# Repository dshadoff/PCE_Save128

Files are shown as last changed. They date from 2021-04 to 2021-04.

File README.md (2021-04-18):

# PCE_Save128
FPGA Implementation of reverse-engineered Memory Base 128/Save-Kun device

This project is designed to reimplement the features of the PC Engine's
Save-kun or Memory Base 128 devices in a modern FPGA device rather than a
customized ASIC.

SPI FeRAM is also in use, with the benefit of being non-volatile.

A MachXO2 FPGA was used due to its relatively low cost, internal Flash
reprogrammability, and simple power supply requirements. Additionally, the
TinyFPGA Ax-series of hobbyist boards helped to facilitate the prototyping
process.

The firmware is coded in Veriog using Lattice's Diamond software; the on-chip
SPI interface was not used; instead, a very limited set of SPI commands is
custom-written for communication with the FeRAM chip.

This repository includes the following folders:

EAGLE :
- these files are the project deisgn files for the PC Board in EAGLE
- Additional information for SMD assembly by JLCPCB are also included, files bom.csv and assembly.csv

firmware:
- This is the project folder for Lattice Diamond, using a MachXO2 FPGA of part number "LCMXO2-1200HC-4SG32C" - as found in the TinyFPGA AX2 board (which is used as a sub-assembly)
- key files are:
 - Save128.v - main verilog file
 - top.v - the top-level module
 - Save128.lpf - pin assignment settings file
 - testbench.v - a testbench which assists in visualizing various scenarios in simulation

release:
- Includes both an SRAM image (.bit) and Flash image (.jed).
- Filename base ends in "yyyymmdd" date format.

TODOs:
------
- shrink PC board
- possibly integrate the FPGA directly onto the main PC board
- design an enclosure of some sort

This is prototype software, and as such has been minimally tested.
Use at your own risk.

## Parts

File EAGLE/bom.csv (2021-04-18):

Qty | Designator | Footprint | Comment | LCSC Part # (optional) | Description (optional)
1 | J1 | CONN_08";1X08" | Do not mount | Do not mount | Multi connection point. Often used as Generic Header-pin footprint for 0.1 inch spaced/style header connections
2 | J2, J3 | MD80SGK | Do not mount | Do not mount | Circular DIN Connectors mini-DIN, 8P jack, rt, through hole, full shield
2 | J4, J5 | 1X12 | Do not mount | Do not mount | Multi connection point. Often used as Generic Header-pin footprint for 0.1 inch spaced/style header connections
1 | J6 | 1X02 | Do not mount | Do not mount | Multi connection point. Often used as Generic Header-pin footprint for 0.1 inch spaced/style header connections
1 | J7 | 1X06_NO_SILK | Do not mount | Do not mount | Multi connection point. Often used as Generic Header-pin footprint for 0.1 inch spaced/style header connections
8 | C1, C2, C6, C7, C8, C9, C10, C11 | C0603 | 0.1uF 50V | C14663 | Yageo CC0603KRX7R9BB104 100NF 50V 0603
2 | C3, C4 | C0603 | 1uF 50V | C15849 | Samsung CL10A105KB8NNNC 1uF 50V 0603
1 | C5 | C0805 | 10uF 25V | C15850 | Samsung CL21A106KAYNNNE 10uF 25V 0805
1 | LED1 | LEDC1608X60N | Yellow | C72038 | Everlight Elec 19-213/Y2C-CQ2R2L/3T(CY) 0603
1 | LED2 | LEDC1608X50N | Green | C72043 | Everlight Elec 19-217/GHC-YR1S2/3T 0603
1 | LED3 | LEDC1608X50N | Red | C2286 | Hubei KENTO Elec KT-0603R 0603
1 | R1 | R0603 | 4.7K | C23162 | Uniroyal Elec 0603WAF4701T5E 0603
5 | R2, R21, R22, R23, R24 | R0603 | 47K | C25819 | Uniroyal Elec 0603WAF4702T5E 0603
2 | R3, R15 | R0603 | 3.3K | C22978 | Uniroyal Elec 0603WAF3301T5E 0603
5 | R13, R16, R18, R19, R20 | R0603 | 330 | C23138 | Uniroyal Elec 0603WAF3300T5E 0603
3 | IC1, IC2, IC3 | SM-8_2.8x3.0x0.65P | SN74LVC2T45DCTR | C22672 | 2-Bit Bus Transceiver, Translation SSOP8 SN74LVC2T45DCTR, Voltage Level Translator, Bus Transceiver LVC, 3-State 1.65
1 | IC4 | SOIC-8_3.9x4.9x1.27P | FM25V10-G | C44173 | F-RAM,128KB,SPI,40MHz,3V,SOIC8 FM25V10-G Serial-SPI FRAM Memory, 1Mbit, 2 3.6 V 8-Pin SOIC
1 | IC5 | SOIC-16_3.9x9.9x1.27P | SN74HC157D | C6823 | Quadruple 2-Line To 1-Line Data Selectors/Multiplexers
1 | IC6 | SOT-23-3 | MCP1700T-3302E_TT | C39051 | LDO voltage regulator 250mA Isupply 1uA

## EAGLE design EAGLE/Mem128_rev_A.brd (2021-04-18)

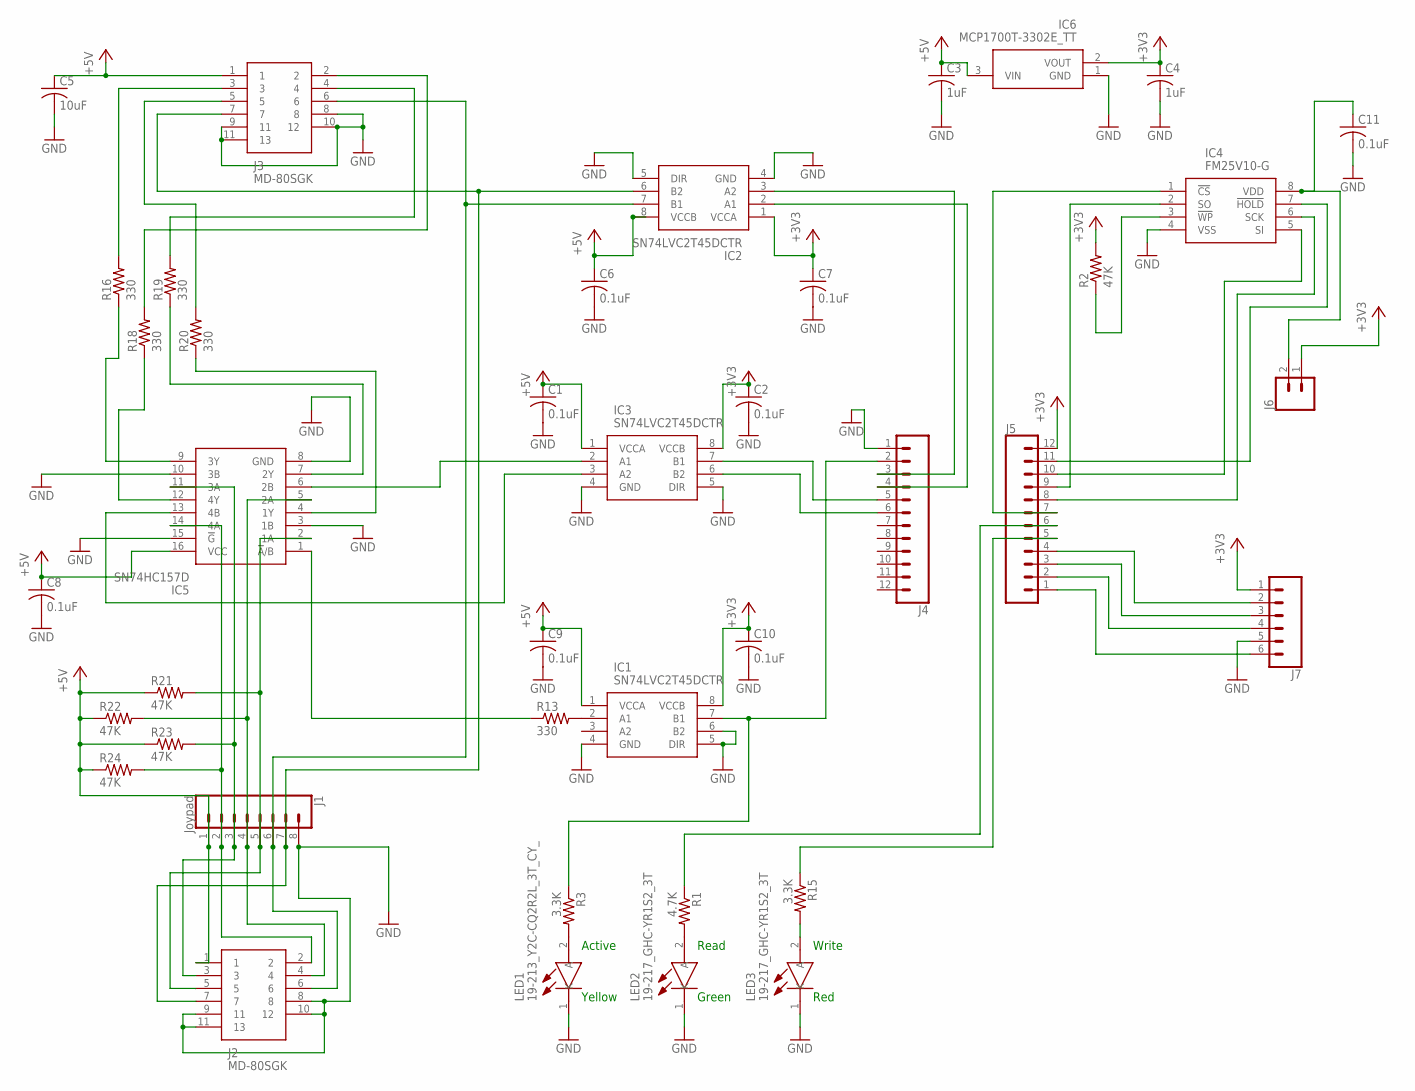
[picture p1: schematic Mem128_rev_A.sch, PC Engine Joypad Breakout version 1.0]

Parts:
C1, C2, C6, C7, C8, C9, C10, C11: 0.1uF; C0603
C3, C4: 1uF; C0603
C5: 10uF; C0805
IC1, IC2, IC3: SN74LVC2T45DCTR; SOP65P400X130-8N
IC4: FM25V10-G; SOIC127P602X173-8N
IC5: SN74HC157D; SOIC127P600X175-16N
IC6: MCP1700T-3302E_TT; SOT95P237X112-3N
J1: Joypad; 1X08
J2, J3: MD-80SGK; MD80SGK
J4, J5: CONN_12; 1X12
J6: CONN_02; 1X02
J7: CONN_06NO_SILK_FEMALE_PTH; 1X06_NO_SILK
LED1: 19-213_Y2C-CQ2R2L_3T_CY_; LEDC1608X60N
LED2: 19-217_GHC-YR1S2_3T; LEDC1608X50N
LED3: 19-217_GHC-YR1S2_3T; LEDC1608X50N; MANUFACTURER_PART_NUMBER KT-0603R
R1: 4.7K; R0603
R2, R21, R22, R23, R24: 47K; R0603
R3, R15: 3.3K; R0603
R13, R16, R18, R19, R20: 330; R0603

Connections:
+3V3: C2.1, C4.1, C7.1, C10.1, IC1.8 (VCCB), IC2.1 (VCCA), IC3.8 (VCCB), IC6.2 (VOUT), J5.12, J6.1, J7.1, R2.2
+5V: C1.1, C3.1, C5.1, C6.1, C8.1, C9.1, IC1.1 (VCCA), IC2.8 (VCCB), IC3.1 (VCCA), IC5.16 (VCC), IC6.3 (VIN), J1.1, J2.1, J3.1, R21.1, R22.1, R23.1, R24.1
CLR: IC2.6 (B2), J1.7, J2.7, J3.7
D6: J5.5, R15.1
D10: J5.6, R1.1
D11: IC1.7 (B1), J4.2, R3.1
GND: C1.2, C2.2, C3.2, C4.2, C5.2, C6.2, C7.2, C8.2, C9.2, C10.2, C11.2, IC1.4 (GND), IC1.5 (DIR), IC1.6 (B2), IC2.4 (GND), IC2.5 (DIR), IC3.4 (GND), IC3.5 (DIR), IC4.4 (VSS), IC5.3 (1B), IC5.8 (GND), IC5.10 (3B), IC5.15 (!G), IC6.1 (GND), J1.8, J2.8, J2.9 (11), J2.10 (12), J2.11 (13), J3.8, J3.9 (11), J3.10 (12), J3.11 (13), J4.1, J7.5, LED1.1 (K), LED2.1 (K), LED3.1 (K)
unnamed: LED2.2 (A), R1.2
unnamed: IC5.11 (3A), J1.3, J2.3, R23.2
unnamed: IC5.14 (4A), J1.2, J2.2, R24.2
unnamed: LED1.2 (A), R3.2
unnamed: IC4.7 (!HOLD), J5.11
unnamed: IC4.6 (SCK), J5.8
unnamed: J3.5, R20.2
unnamed: J3.4, R19.2
unnamed: J3.3, R16.2
unnamed: C11.1, IC4.8 (VDD), J6.2
unnamed: IC5.1 (!A!/B), R13.1
unnamed: IC1.2 (A1), R13.2
unnamed: IC5.5 (2A), J1.4, J2.4, R22.2
unnamed: IC5.9 (3Y), R16.1
unnamed: IC5.2 (1A), J1.5, J2.5, R21.2
unnamed: IC3.2 (A1), IC5.6 (2B)
unnamed: IC5.12 (4Y), R18.1
unnamed: IC5.4 (1Y), R20.1
unnamed: J3.2, R18.2
unnamed: IC5.7 (2Y), R19.1
unnamed: IC4.3 (!WP), R2.1
unnamed: IC4.1 (!CS), J5.7
unnamed: IC4.5 (SI), J5.10
unnamed: IC3.3 (A2), IC5.13 (4B)
unnamed: IC4.2 (SO), J5.9
unnamed: IC2.3 (A2), J4.3
unnamed: IC3.7 (B1), J4.5
unnamed: IC3.6 (B2), J4.6
unnamed: J5.1, J7.6
unnamed: LED3.2 (A), R15.2
unnamed: J5.2, J7.4
unnamed: J5.3, J7.3
unnamed: J5.4, J7.2
RX: IC2.2 (A1), J4.4
SEL: IC2.7 (B1), J1.6, J2.6, J3.6

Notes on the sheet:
Active
Read
Write
Yellow
Green
Red

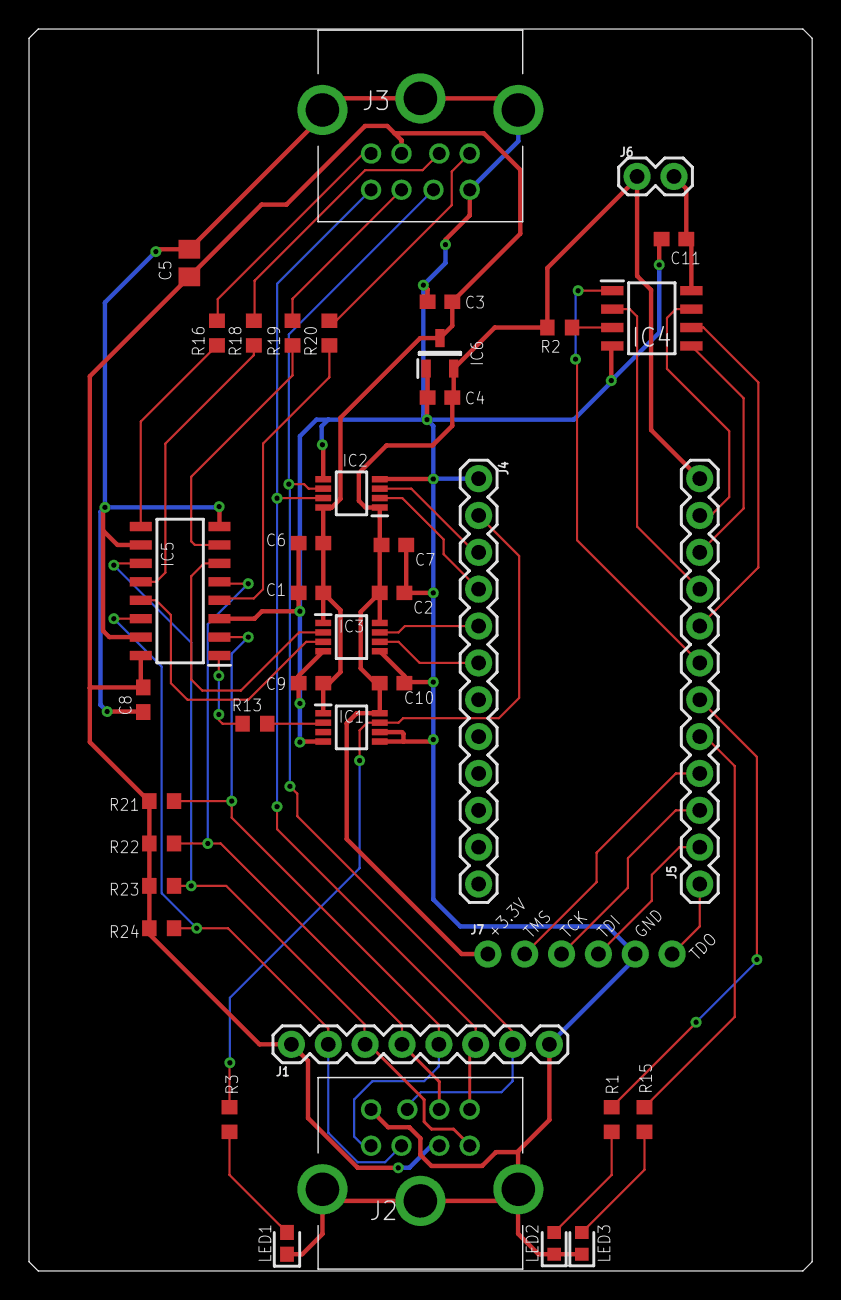
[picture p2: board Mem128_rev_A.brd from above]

Board: 2 copper layers, 54.0 x 85.6 mm, 40 parts (0 on the bottom side), 42 nets.

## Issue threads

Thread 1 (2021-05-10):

iCE40?  Parallel memory?

GravisZro, 2021-05-10:
Just curious if you might be interested in perhaps modifying the project to use a Lattice iCE40 chip (e.g. [ICE40HX1K-VQ100](https://www.digikey.com/en/products/detail/lattice-semiconductor-corporation/ICE40HX1K-VQ100/3083577)) since there is [an open source toolchain](http://www.clifford.at/icestorm/) and perhaps avoid SPI altogether by using a memory chip with a parallel interface (e.g. [MR0A08BYS35](https://www.digikey.com/en/products/detail/everspin-technologies-inc/MR0A08BYS35/1930954)).  Yes, the iCE40 will need another power regulator but it's not too complex.  There is [a cheap iCE40 dev board](http://www.latticesemi.com/icestick) you can get if that is a concern.

Just some ideas to consider but if you're not interested in making changes, that's OK too.

GravisZro, 2021-05-10:
Ugh... QFN is the worst.  Looking forward to the new solution.

Closed 2021-05-10.

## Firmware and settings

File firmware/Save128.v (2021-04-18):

module MB128 (
	input		clk_sys,	// system clock
	input wire	reset_n,	// reset - active low

	input  i_Clk,			// Joypad Clr/Reset line, clocks the SPI-like MB128 protocol 
	input  i_Data,			// Joypad Sel line, provides data to the SPI-like MB128 protocol

	output o_Active,
    output o_Data,
    output o_Ident,

	output o_ReadLED,
	output o_WriteLED,

	output sp_cs_n,
	output sp_clk,
	input  sp_miso,
	output sp_mosi,
	output sp_hold_n
);


  // constants - SPI Commands
  parameter   SPI_READ_CMD		= 8'h3;
  parameter   SPI_WRITE_CMD		= 8'h2;
  parameter   SPI_WREN_CMD		= 8'h6;

  // constants - STATE MACHINE states
  // STATE GROUP 1 - Request identification
  parameter   STATE_IDLE         = 4'b0000;
  parameter   STATE_A8_A1        = 4'b0001;
  parameter   STATE_A8_A2        = 4'b0010;
  // STATE GROUP 2 - Synced; request information
  parameter   STATE_REQ          = 4'b0011;
  parameter   STATE_ADDR         = 4'b0100;
  parameter   STATE_LENBITS      = 4'b0101;
  parameter   STATE_LENBYTES     = 4'b0110;
  // STATE GROUP 3 - Synced; in-transfer states
  parameter   STATE_READ         = 4'b0111;
  parameter   STATE_READBITS     = 4'b1000;
  parameter   STATE_READ_TRAIL   = 4'b1001;
  parameter   STATE_WRITE        = 4'b1010;
  parameter   STATE_WRITEBITS    = 4'b1011;
  parameter   STATE_WRITE_TRAIL  = 4'b1100;
  // STATE FINAL - ERROR
  parameter   STATE_ERROR        = 4'b1111;
  
  // incoming MB128 commands
  parameter   CMD_WRITE          = 1'b0;
  parameter   CMD_READ           = 1'b1;

  // REGISTERS
  
  // Used for debouncing the input 'clocking' to the MB128
  // from the host console.  This clocking is roughly 150-200KHz
  // and comes over a cable between 10cm and 50cm.
  //
  // Since the core clock is just over 40MHz, we wait for 30 consecutive
  // reads of the same value before recognizing a transition (~750ns settling)
  // This could probably be reduced somewhat.
  //
  reg			i_Clk_Prev		= 1'b0;
  reg			i_Clk_Debounce	= 1'b0;
  reg [29:0]	i_Clk_ShiftReg	= 30'b000000_00000000_00000000_00000000;

  // State machine for the MB128
  //
  reg [3:0]  r_State            = STATE_IDLE;
  reg [3:0]  r_State_Prev       = STATE_IDLE;
  
  // incoming data
  reg [7:0]  r_Register         = 8'b0;
  
  // incoming request type
  reg         r_Req              = CMD_READ;
  
  // r_Active is used for the assertion of whether MB128 is
  // returning data, or the downstream joypad.  We de-activate
  // in two stages, remaining active for the entire 'high' period
  // of the incoming joypad clock signal, de-asserting when it
  // transitions low.  Since the always blocks are all posedge, this
  // is decommissioned by the fast clock, based on the level of the slow clock.
  //
  reg         r_Active           = 1'b0;
  reg         r_Stop_Active      = 1'b0;

  // input data from transaction; r_MB128_Addr_Curr is a current-address counter
  //
  reg [5:0]  r_Bit_Count        = 6'b000000;
  reg [16:0] r_MB128_Addr       = 17'b00000000000000000;
  reg [16:0] r_MB128_Addr_Curr  = 17'b00000000000000000;
  reg [16:0] r_MB128_Bytes      = 17'b00000000000000000;
  reg [2:0]  r_MB128_Bits       = 3'b000;
  
  // Data to output - may differ between Clk level '1' and Clk level '0'
  //
  reg [3:0]  r_Pos_Edge         = 4'b0000;
  reg [3:0]  r_Neg_Edge         = 4'b0000;

  reg [7:0]  r_Read_Byte        = 8'b00000000;
  reg [7:0]  r_Write_Byte       = 8'b00000000;
  
  // On sub-byte writes, we must read the byte, rewrite only those bits,
  // and rewrite the byte
  // This data is read at the beginning, and saved until the end.
  //
  reg [7:0]  r_FetchWrite_Byte  = 8'b00000000;
  
  // Visualization registers (only used during simulation):
  reg   r_StateAddr        = 1'b0;
  reg   r_StateLenBits     = 1'b0;
  reg   r_StateLenBytes    = 1'b0;
  reg   r_StateReadByte    = 1'b0;
  reg   r_StateReadBit     = 1'b0;
  reg   r_StateReadTrail   = 1'b0;
  reg   r_StateWriteByte   = 1'b0;
  reg   r_StateWriteBit    = 1'b0;
  reg   r_StateWriteTrail  = 1'b0;
  
  // light LEDs based on transaction type
  //
  reg   o_ReadLED			= 1'b0;
  reg   o_WriteLED			= 1'b0;

  // these are set in the 'slow clock' loop, based on PCE transactions
  // they trigger processes inside the 'fast clock' SPI loop
  //
  reg   trigger_read		= 1'b0;
  reg   trigger_write		= 1'b0;
  reg   trigger_fetchwrite	= 1'b0;			// on a partial byte write, this is the fetch-before-alter
  reg   trigger_wren		= 1'b0;

  reg [7:0] ram_data		= 1'b0;


  reg  [5:0] cmd_len = 6'b100000;  // 32;
  reg  [4:0] rw_len = 5'b01000;  // 8
  reg  [31:0] cmd_buf = 32'b00000011_00000000_00000000_00000000; // = { SPI 3 = READ; 24 bit addr = 0 };
  reg  [15:0] rd_buf = 16'b00000000;
  reg  [15:0] wr_buf = 16'b00000000;
  reg  sp_go   = 0;


  reg  [7:0]  spi_cmd = 0;
  reg  [23:0] spi_addr = 0;
  reg  [7:0]  spi_dataout = 0;


  reg init = 0;
  reg [1:0] sp_phase = 2'b00;
  reg sp_clk = 0;
  reg sp_cs_n = 1;
  reg sp_hold_n = 0;
  reg sp_active = 0;
  reg sp_end_desel = 0;
  reg sp_mosi = 0;
  reg read_in_transit = 0;
  reg write_in_transit = 0;
  reg fetchwrt_in_transit = 0;

  

// TODO: validate that all appropriate registers are reset at RESET and transition back to STATE_IDLE
//
  always @(posedge clk_sys)
	begin

	  if (~reset_n) begin
		r_State            <= STATE_IDLE;
		r_MB128_Addr       <= 17'b00000000000000000;
		r_MB128_Addr_Curr  <= 17'b00000000000000000;
		r_MB128_Bytes      <= 17'b00000000000000000;
		r_MB128_Bits       <= 3'b000;
		r_Bit_Count        <= 6'b000000;
		r_Register         <= 8'b00000000;
		r_Active           <= 1'b0;
		r_Stop_Active      <= 1'b0;
		r_Pos_Edge         <= 4'b0000;
		r_Neg_Edge         <= 4'b0000;
		o_ReadLED          <= 1'b0;
	    o_WriteLED         <= 1'b0;

		trigger_read       <= 1'b0;
		trigger_write      <= 1'b0;
		trigger_fetchwrite <= 1'b0;
		ram_data           <= 8'b00000000;
	  end



	i_Clk_ShiftReg <= {i_Clk_ShiftReg[28:0], i_Clk };

	if (i_Clk_ShiftReg == 30'b000000_00000000_00000000_00000000)
		i_Clk_Debounce <= 0;

	if (i_Clk_ShiftReg == 30'b111111_11111111_11111111_11111111)
		i_Clk_Debounce <= 1;
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

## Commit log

2020-10-13 Implement simple bit-bang SPI
2020-10-18 Get SPI working...sort of
    SPI read function roks for first read; subsequent accesses need to be debugged.
2020-10-18 SPI read working a little bit more
    HOLD functionality still not working properly, but subsequent full SPI transactions now work.
    [Save128.v]
2021-04-17 Nearly working
    [compile.cfg, library.cfg, projlib.cfg]
2021-04-18 Some fixes diuring simulation
    [Save128.v]
2021-04-18 Clean up simulation folders, create release
    [compile.cfg, library.cfg, projlib.cfg]
2021-04-18 Add EAGLE PC Board design files
    [Mem128_rev_A.brd, Mem128_rev_A.sch, assembly.csv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]
2021-04-18 Correct a couple of warnings
    [Save128.v]

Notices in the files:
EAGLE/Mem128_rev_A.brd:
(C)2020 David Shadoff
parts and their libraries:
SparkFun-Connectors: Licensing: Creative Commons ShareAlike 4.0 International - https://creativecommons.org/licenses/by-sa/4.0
